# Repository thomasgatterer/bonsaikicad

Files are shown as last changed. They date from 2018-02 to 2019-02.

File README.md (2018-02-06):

# bonsaikicad

Hier die (pädagogisch vereinfachte) Simulation des Lerncomputers:
https://bonsai.pinyto.de/

Und hier die Seite des Lehrers der das Projekt ins Leben gerufen hat (ist übrigens der Vater vom Programmierer der Simulation):
http://www.hsg-kl.de/faecher/inf/material/bonsai/

Weiterführendes:
https://tams-www.informatik.uni-hamburg.de/applets/baukasten/DA/VNR_Einleitung.html
www.saar.de/~awa/data/Von-Neumann-Rechner.pdf
informatik-erleben.aau.at/einheiten/uebersicht.php?id0d3

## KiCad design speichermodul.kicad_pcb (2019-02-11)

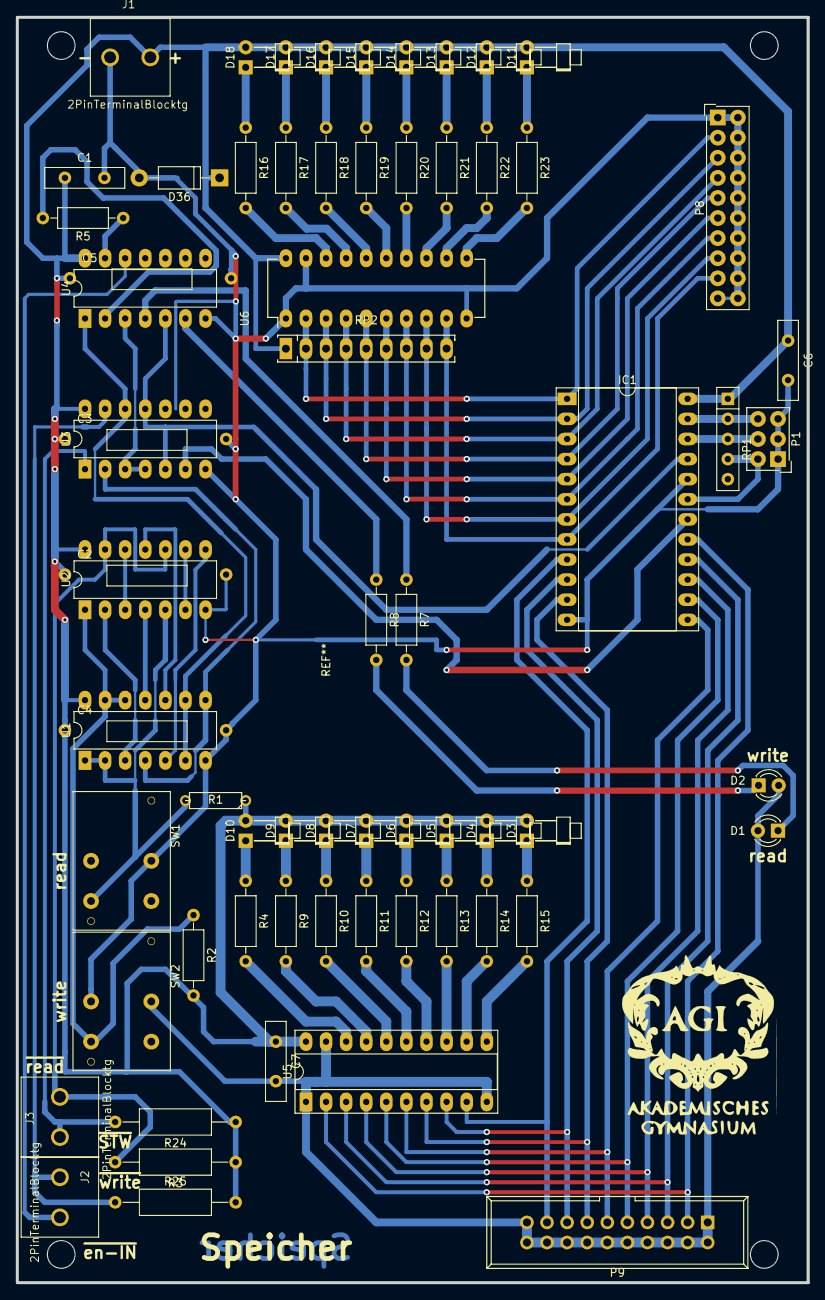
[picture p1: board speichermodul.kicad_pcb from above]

Board: 2 copper layers, 100.0 x 160.0 mm, 67 parts (0 on the bottom side), 76 nets.

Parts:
C1, C6, C7: 100n; C_Disc_D10.0mm_W2.5mm_P5.00mm
C2, C3, C4, C5: 100n; yyDisc_D10.0mm_W2.5mm_P.00mm
D1, D2: LED; LED_D3.0mm
D3, D4, D5, D6, D7, D8, D9, D10, D11, D12, D13, D14, D15, D16, D17, D18: LED; LED_D1.8mm_W1.8mm_H2.4mm_Horizontal_O3.81mm_Z8.2mm
D36: D; D_DO-41_SOD81_P10.16mm_Horizontal
IC1: 6116; DIP-24_W15.24mm_Socket_LongPads
J1, J2, J3: 2PinTerminalBlocktg
P1: CONN_3X2; SDL-106-X-XX_2x03
P8: CONN_02X10; SDL-120-X-XX_2x10
P9: CONN_02X10; IDC_Header_Straight_20pins
R1: 1,7k; R3
R2: 4,7k; R_Axial_DIN0207_L6.3mm_D2.5mm_P10.16mm_Horizontal
R3, R24, R25: 4,7k; R_Axial_DIN0309_L9.0mm_D3.2mm_P15.24mm_Horizontal
R4, R9, R10, R11, R12, R13, R14, R15, R16, R17, R18, R19, R20, R21, R22, R23: 330; R_Axial_DIN0207_L6.3mm_D2.5mm_P10.16mm_Horizontal
R5: 0; R_Axial_DIN0207_L6.3mm_D2.5mm_P10.16mm_Horizontal
R7, R8: R; R_Axial_DIN0207_L6.3mm_D2.5mm_P10.16mm_Horizontal
RP1: R_PACK4BUSSED; R_Array_SIP5
RP2: R_PACK8BUSSED; SIP9_Housing_BigPads
SW1, SW2: SW_PUSH-tg; SW_PUSH_LCD_E3_SAxxxx_tg_V2
U1: 7400; DIP-14_W7.62mm_LongPads
U2, U3: 74LS08; DIP-14_W7.62mm_LongPads
U4: 74LS14; DIP-14_W7.62mm_LongPads
U5: 74LS540; DIP-20_W7.62mm_Socket_LongPads
U6: 74LS540; DIP-20_W7.62mm_LongPads

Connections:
/A0: IC1.1, P8.3, RP2.2, U6.2
/A1: IC1.2, P8.5, RP2.3, U6.3
/A2: IC1.3, P8.7, RP2.4, U6.4
/A3: IC1.4, P8.9, RP2.5, U6.5
/A4: IC1.5, P8.11, RP2.6, U6.6
/A5: IC1.6, P8.13, RP2.7, U6.7
/A6: IC1.7, P8.15, RP2.8, U6.8
/A7: IC1.8, P8.17, RP2.9, U6.9
/A8: IC1.23, P1.2, RP1.2
/A9: IC1.22, P1.4, RP1.3
/A10: IC1.19, P1.6, RP1.4
/D0: IC1.17, P9.3, U5.2
/D1: IC1.16, P9.5, U5.3
/D2: IC1.15, P9.7, U5.4
/D3: IC1.14, P9.9, U5.5
/D4: IC1.13, P9.11, U5.6
/D5: IC1.11, P9.13, U5.7
/D6: IC1.10, P9.15, U5.8
/D7: IC1.9, P9.17, U5.9
AUTO: J3.2, R3.2, U2.10, U2.13
EN: J2.2, U4.12
GND: C1.2, C2.2, C3.2, C4.2, C5.2, C6.2, C7.2, D1.2, D2.2, D36.2, IC1.12, IC1.20, J1.1, P1.1, P1.3, P1.5, P8.1, P8.2, P8.4, P8.6, P8.8, P8.10, P8.12, P8.14, P8.16, P8.18, P8.19, P8.20, P9.1, P9.2, P9.4, P9.6, P9.8, P9.10, P9.12, P9.14, P9.16, P9.18, P9.19, P9.20, SW1.0, SW2.0, U1.7, U2.7, U3.7, U4.7, U5.1, U5.10, U5.19, U6.1, U6.10, U6.19
unnamed: D1.1, R7.2
unnamed: D2.1, R8.2
unnamed: D3.1, R15.1
unnamed: D4.1, R14.1
unnamed: D5.1, R13.1
unnamed: D6.1, R12.1
unnamed: D7.1, R11.1
unnamed: D8.1, R10.1
unnamed: D9.1, R9.1
unnamed: D10.1, R4.1
unnamed: D11.1, R23.1
unnamed: D12.1, R22.1
unnamed: D13.1, R21.1
unnamed: D14.1, R20.1
unnamed: D15.1, R19.1
unnamed: D16.1, R18.1
unnamed: D17.1, R17.1
unnamed: D18.1, R16.1
unnamed: IC1.18, U3.6
unnamed: IC1.21, U3.5, U3.11, U4.5
unnamed: R1.2, SW1.1, U1.1, U1.2, U2.5
unnamed: R2.1, SW2.1, U1.12, U1.13, U2.1
unnamed: R4.2, U5.18
unnamed: R5.1, U4.13
unnamed: R5.2, U4.2
unnamed: R7.1, U4.4
unnamed: R8.1, U4.6
unnamed: R9.2, U5.17
unnamed: R10.2, U5.16
unnamed: R11.2, U5.15
unnamed: R12.2, U5.14
unnamed: R13.2, U5.13
unnamed: R14.2, U5.12
unnamed: R15.2, U5.11
unnamed: R16.2, U6.18
unnamed: R17.2, U6.17
unnamed: R18.2, U6.16
unnamed: R19.2, U6.15
unnamed: R20.2, U6.14
unnamed: R21.2, U6.13
unnamed: R22.2, U6.12
unnamed: R23.2, U6.11
unnamed: U1.3, U2.2
unnamed: U1.4, U1.8, U3.2
unnamed: U1.5, U2.8
unnamed: U1.6, U1.9, U3.12, U4.1
unnamed: U1.10, U2.11
unnamed: U1.11, U2.4
unnamed: U2.6, U2.9
unnamed: U2.3, U2.12
unnamed: U3.3, U3.4, U4.3
RD: J3.1, R24.2, U3.1
VCC: C1.1, C2.1, C3.1, C4.1, C5.1, C6.1, C7.1, D3.2, D4.2, D5.2, D6.2, D7.2, D8.2, D9.2, D10.2, D11.2, D12.2, D13.2, D14.2, D15.2, D16.2, D17.2, D18.2, D36.1, IC1.24, J1.2, R1.1, R2.2, R3.1, R24.1, R25.2, RP1.1, RP2.1, U1.14, U2.14, U3.14, U4.14, U5.20, U6.20
WR: J2.1, R25.1, U3.13

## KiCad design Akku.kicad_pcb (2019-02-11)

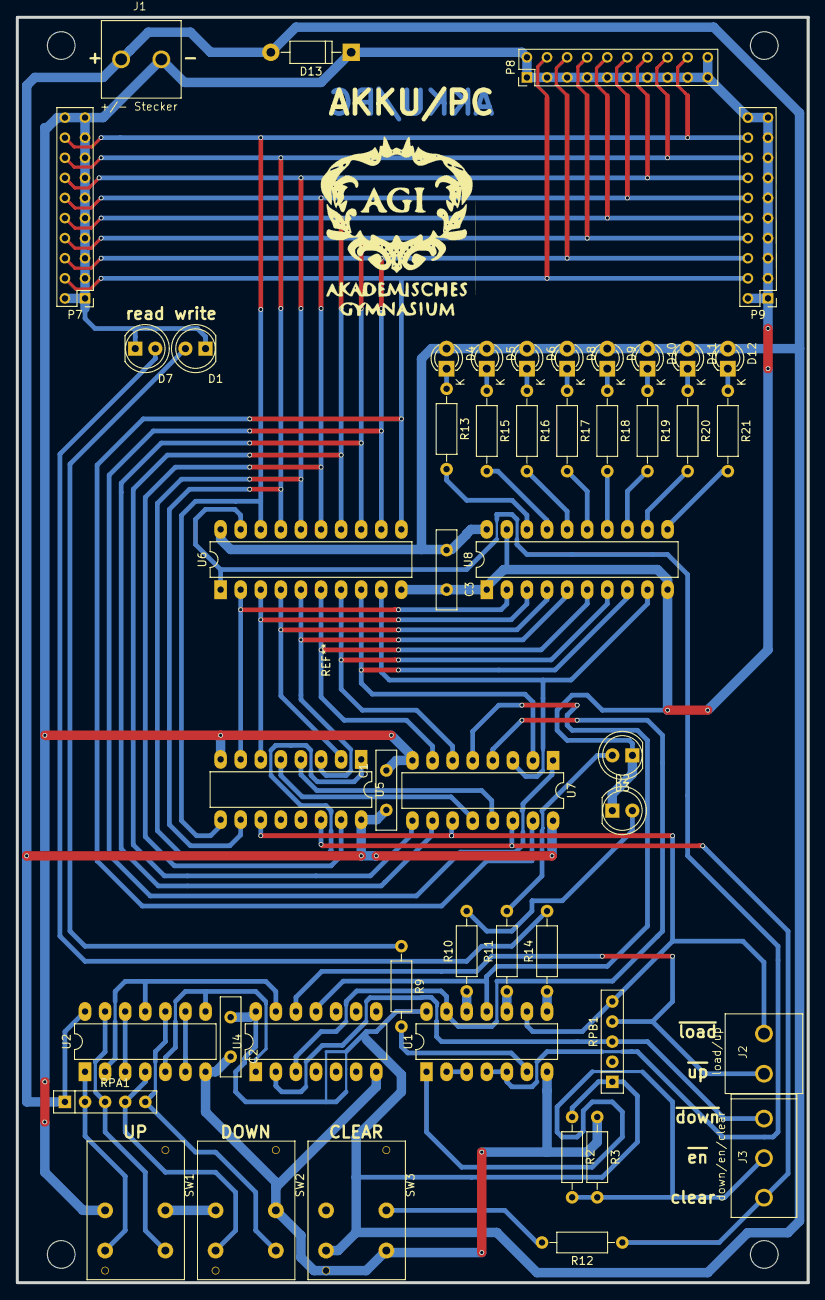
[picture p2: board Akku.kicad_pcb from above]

Board: 2 copper layers, 100.0 x 160.0 mm, 49 parts (0 on the bottom side), 62 nets.

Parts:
C1, C2, C3: C; C_Disc_D10.0mm_W2.5mm_P5.00mm
D1, D2, D3, D7: LED; LED_D5.0mm_FlatTop
D4, D5, D6, D8, D9, D10, D11, D12: LED; LED-3MM
D13: D; D_DO-41_SOD81_P10.16mm_Horizontal
J1: +/- Stecker; 2PinTerminalBlocktg
J2: load/up; 2PinTerminalBlocktg
J3: down/en/clear; 3PinTerminalBlocktg
P7, P8, P9: CONN_02X10; Pin_Header_Straight_2x10_Pitch2.00mmBonsai.pretty
R2, R3, R9, R10, R11, R12, R13, R14, R15, R16, R17, R18, R19, R20, R21: R; R_Axial_DIN0207_L6.3mm_D2.5mm_P10.16mm_Horizontal
RPA1: R_PACK4BUSSED; R_Array_SIP5
RPB1: R_PACK4BUSSED; R_Array_SIP5
SW1: UP_Bonsai_SWITCH_INV; SW_PUSH_LCD_E3_SAxxxx_tg_V2
SW2: DOWN_Bonsai_SWITCH_INV; SW_PUSH_LCD_E3_SAxxxx_tg_V2
SW3: CLR_Bonsai_SWITCH_INV; SW_PUSH_LCD_E3_SAxxxx_tg_V2
U1: 74HC14; DIP-14_W7.62mm_LongPads
U2: 7400; DIP-14_W7.62mm_LongPads
U4: 7408; DIP-14_W7.62mm_LongPads
U5, U7: 74LS193; DIP-16_W7.62mm_LongPads
U6: 74LS541; DIP-20_W7.62mm_LongPads
U8: 74LS540; DIP-20_W7.62mm_LongPads

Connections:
/a0: P7.19, P8.19, P9.19, U5.9, U6.18
/a1: P7.18, P8.18, P9.18, U5.10, U6.17
/a2: P7.17, P8.17, P9.17, U5.1, U6.16
/a3: P7.16, P8.16, P9.16, U5.15, U6.15
/a4: P7.15, P8.15, P9.15, U6.14, U7.9
/a5: P7.14, P8.14, P9.14, U6.13, U7.10
/a6: P7.13, P8.13, P9.13, U6.12, U7.1
/a7: P7.12, P8.12, P9.12, U6.11, U7.15
CLR: J3.3, R12.1, U5.14, U7.14
GND: C1.1, C2.1, C3.1, D1.1, D2.1, D3.1, D7.1, D13.1, J1.2, P7.1, P7.2, P7.3, P7.4, P7.5, P7.6, P7.7, P7.8, P7.9, P7.10, P7.11, P7.20, P8.1, P8.2, P8.3, P8.4, P8.5, P8.6, P8.7, P8.8, P8.9, P8.10, P8.11, P8.20, P9.1, P9.2, P9.3, P9.4, P9.5, P9.6, P9.7, P9.8, P9.9, P9.10, P9.11, P9.20, R3.1, SW1.0, SW2.0, SW3.2, SW3.6, U1.7, U2.7, U4.7, U5.8, U6.10, U7.8, U8.1, U8.10, U8.19
unnamed: D1.2, R9.1
unnamed: D2.2, R10.2
unnamed: D3.2, R11.2
unnamed: D4.1, R13.1
unnamed: D5.1, R15.1
unnamed: D6.1, R16.1
unnamed: D7.2, R14.2
unnamed: D8.1, R17.1
unnamed: D9.1, R18.1
unnamed: D10.1, R19.1
unnamed: D11.1, R20.1
unnamed: D12.1, R21.1
unnamed: R9.2, U1.6
unnamed: R10.1, U1.12
unnamed: R11.1, U1.10
unnamed: R12.2, SW3.0
unnamed: R13.2, U8.18
unnamed: R14.1, U1.8
unnamed: R15.2, U8.17
unnamed: R16.2, U8.16
unnamed: R17.2, U8.15
unnamed: R18.2, U8.14
unnamed: R19.2, U8.13
unnamed: R20.2, U8.12
unnamed: R21.2, U8.11
unnamed: U1.2, U1.3
unnamed: U1.4, U1.5, U6.1, U6.19
unnamed: U1.11, U4.11, U7.5
unnamed: U1.13, U4.3, U7.4
unnamed: U2.5, U2.8, U4.1
unnamed: U2.6, U2.9
unnamed: U2.2, U2.11, U4.13
unnamed: U2.3, U2.12
unnamed: U5.2, U6.4, U8.4
unnamed: U5.3, U6.5, U8.5
unnamed: U5.4, U7.13
unnamed: U5.5, U7.12
unnamed: U5.6, U6.3, U8.3
unnamed: U5.7, U6.2, U8.2
unnamed: U6.6, U7.7, U8.6
unnamed: U6.7, U7.6, U8.7
unnamed: U6.8, U7.2, U8.8
unnamed: U6.9, U7.3, U8.9
RPA1: RPA1.2, SW1.1, U2.1
RPA2: RPA1.3, SW1.2, U2.13
RPA3: RPA1.4, SW2.1, U2.4
RPA4: RPA1.5, SW2.2, U2.10
RPB2: J3.1, RPB1.3, U4.2
RPB3: J2.2, RPB1.4, U4.12
RPB4: J2.1, RPB1.5, U1.9, U5.11, U7.11
VCC: C1.2, C2.2, C3.2, D4.2, D5.2, D6.2, D8.2, D9.2, D10.2, D11.2, D12.2, D13.2, J1.1, R2.1, RPA1.1, RPB1.1, SW3.1, U1.14, U2.14, U4.14, U5.16, U6.20, U7.16, U8.20
^enable: J3.2, R2.2, R3.2, U1.1

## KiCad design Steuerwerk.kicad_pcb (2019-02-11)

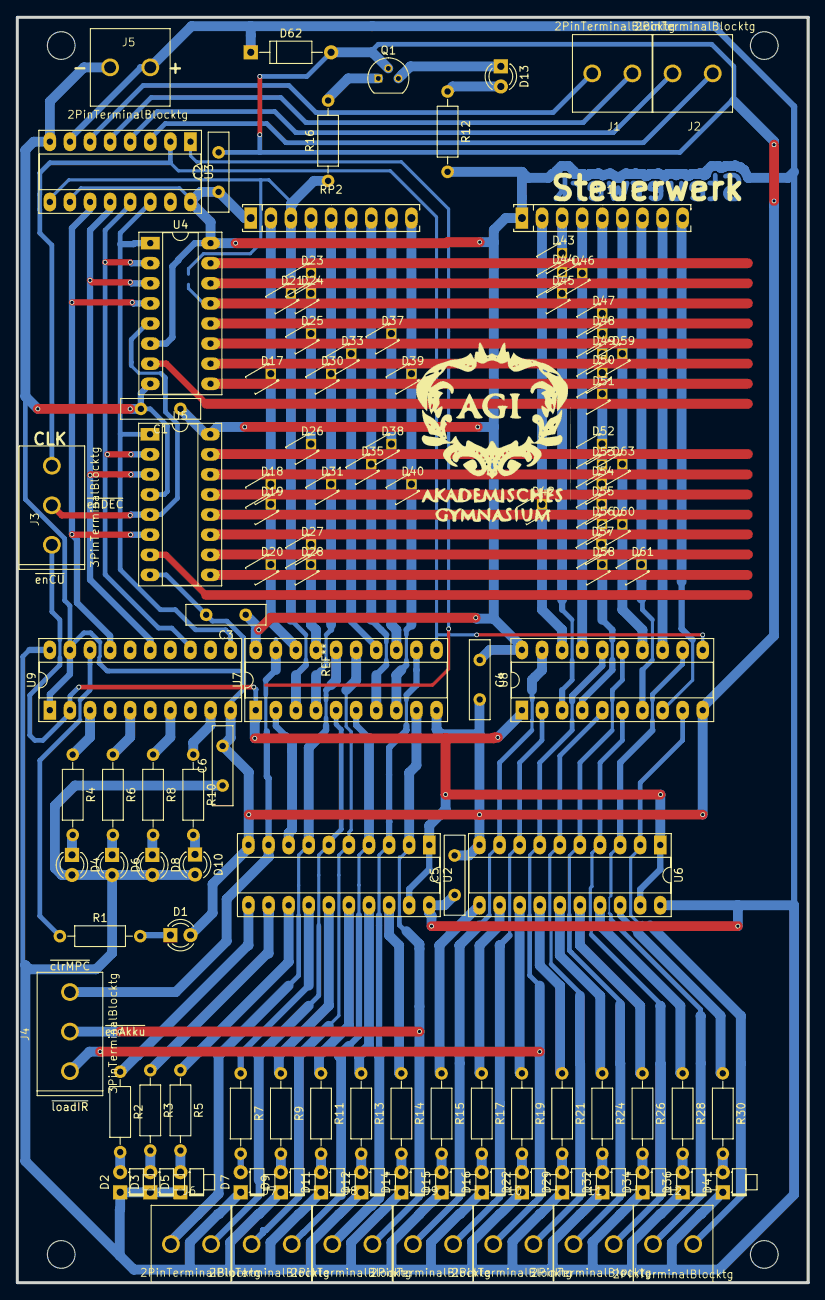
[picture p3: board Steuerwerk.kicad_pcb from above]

Board: 2 copper layers, 100.0 x 160.0 mm, 115 parts (0 on the bottom side), 104 nets.

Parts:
C1, C2, C3, C4, C5, C6: 100n; C_Disc_D10.0mm_W2.5mm_P5.00mm
D1, D4, D6, D8, D10, D13: LED; LED_D3.0mm
D2, D3, D5, D7, D9, D11, D12, D14, D15, D16, D22, D29, D32, D34, D36, D41: LED; LED_D1.8mm_W1.8mm_H2.4mm_Horizontal_O1.27mm_Z1.6mm
D17, D18, D19, D20, D21, D23, D24, D25, D26, D27, D28, D30, D31, D33, D35, D37, D38, D39, D40, D42, D43, D44, D45, D46, D47, D48, D49, D50, D51, D52, D53, D54, D55, D56, D57, D58, D59, D60, D61, D63: Led_Small; LED_D1.8mm_W3.3mm_H2.4mmBonsai
D62: D; D_A-405_P10.16mm_Horizontal
J1, J2, J5, J6, J7, J8, J9, J10, J11, J12: 2PinTerminalBlocktg
J3, J4: 3PinTerminalBlocktg
Q1: Q_PNP_BCE; TO-92_Molded_Narrow
R1, R2, R3, R4, R5, R6, R7, R8, R9, R10, R11, R12, R13, R14, R15, R16, R17, R19, R21, R24, R26, R28, R30: R; R_Axial_DIN0207_L6.3mm_D2.5mm_P10.16mm_Horizontal
RP1, RP2: R_PACK8BUSSED; SIP9_Housing_BigPads
U2, U6: 74541; DIP-20_W7.62mm_Socket_LongPads
U3: 74LS161; DIP-16_W7.62mm_Socket_LongPads
U4, U5: 74LS138; DIP-16_W7.62mm_Socket_LongPads
U7: 74LS374; DIP-20_W7.62mm_Socket_LongPads
U8: 74LS374; DIP-20_W7.62mm_Socket_LongPadstg
U9: 74ls240; DIP-20_W7.62mm_Socket_LongPads

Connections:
/3: J6.1, U2.7, U7.16
/5: J7.1, U2.5, U7.15
/7: J8.1, U2.3, U7.12
/9: J9.1, U6.9, U8.19
/11: J4.1, J10.1, U6.7, U8.16
/13: J11.1, U6.5, U8.15
/15: J12.1, U6.3, U8.12
/16: J12.2, U6.2, U8.9
/Takt: J3.3, U3.2, U7.11, U8.11
/a1: D17.1, D18.1, D19.1, D20.1, RP2.2, U7.18
/a2: D21.1, R16.1, RP2.3, U3.9, U7.3
/a3: D23.1, D24.1, D25.1, D26.1, D27.1, D28.1, RP2.4, U7.17
/a4: D30.1, D31.1, RP2.5, U7.4
/a5: D33.1, RP2.6, U7.14
/a6: D35.1, RP2.7, U7.7
/a7: D37.1, D38.1, RP2.8, U7.13
/a8: D39.1, D40.1, RP2.9, U7.8
/b1: D42.1, RP1.2, U8.18
/b2: D43.1, D44.1, D45.1, RP1.3, U8.3
/b3: D46.1, RP1.4, U8.17
/b4: D47.1, D48.1, D49.1, D50.1, D51.1, D52.1, D53.1, D54.1, D55.1, D56.1, D57.1, D58.1, RP1.5, U8.4
/b5: D59.1, D60.1, D63.1, RP1.6, U8.14
/b6: D61.1, RP1.7, U8.7
/b7: RP1.8, U8.13
/b8: RP1.9, U8.8
/clrMPC: J4.3, U2.9, U3.1, U7.19
/enAkku: J4.2, J8.2, U2.2, U7.9
/enDEC: J3.2, U4.5, U5.5
/enSTW: J3.1, U2.1, U2.19, U6.1, U6.19, U7.1, U8.1, U9.2
GND: C1.2, C2.2, C3.2, C4.2, C5.2, C6.2, D1.2, D62.2, J5.1, Q1.2, U2.10, U3.8, U4.8, U5.4, U5.8, U6.10, U7.10, U8.10, U9.1, U9.10, U9.19
unnamed: D1.1, R1.2
unnamed: D2.2, R2.2
unnamed: D3.2, R3.2
unnamed: D4.1, R4.2
unnamed: D5.2, R5.2
unnamed: D6.1, R6.2
unnamed: D7.2, R7.2
unnamed: D8.1, R8.2
unnamed: D9.2, R9.2
unnamed: D10.1, R10.2
unnamed: D11.2, R11.2
unnamed: D12.2, R13.2
unnamed: D13.1, Q1.3
unnamed: D13.2, R12.1
unnamed: D14.2, R14.2
unnamed: D15.2, R15.2
unnamed: D16.2, R17.2
unnamed: D17.2, D30.2, D39.2, D50.2, U4.9
unnamed: D18.2, D31.2, D40.2, D54.2, U5.13
unnamed: D19.2, D42.2, D55.2, U5.12
unnamed: D20.2, D28.2, D58.2, D61.2, U5.9
unnamed: D21.2, D24.2, D45.2, U4.13
unnamed: D22.2, R19.2
unnamed: D23.2, D44.2, D46.2, U4.14
unnamed: D25.2, D37.2, D48.2, U4.11
unnamed: D26.2, D38.2, D52.2, U5.15
unnamed: D27.2, D57.2, U5.10
unnamed: D29.2, R21.2
unnamed: D32.2, R24.2
unnamed: D33.2, D49.2, D59.2, U4.10
unnamed: D34.2, R26.2
unnamed: D35.2, D53.2, D63.2, U5.14
unnamed: D36.2, R28.2
unnamed: D41.2, R30.2
unnamed: D43.2, U4.15
unnamed: D47.2, U4.12
unnamed: D51.2, U4.7
unnamed: D56.2, D60.2, U5.11
unnamed: J1.1, U3.5
unnamed: J1.2, U3.6
unnamed: J2.1, U3.3
unnamed: J2.2, U3.4
unnamed: J6.2, U2.6, U7.5
unnamed: J7.2, U2.4, U7.6
unnamed: J9.2, U6.8, U8.2
unnamed: J10.2, U6.6, U8.5
unnamed: J11.2, U6.4, U8.6
unnamed: Q1.1, R16.2
unnamed: R1.1, U9.18
unnamed: R2.1, U2.11
unnamed: R3.1, U2.12
unnamed: R4.1, U9.3
unnamed: R5.1, U2.13
unnamed: R6.1, U9.5
unnamed: R7.1, U2.14
unnamed: R8.1, U9.7
unnamed: R9.1, U2.15
unnamed: R10.1, U9.9
unnamed: R11.1, U2.16
unnamed: R13.1, U2.17
unnamed: R14.1, U2.18
unnamed: R15.1, U6.11
unnamed: R17.1, U6.12
unnamed: R19.1, U6.13
unnamed: R21.1, U6.14
unnamed: R24.1, U6.15
unnamed: R26.1, U6.16
unnamed: R28.1, U6.17
unnamed: R30.1, U6.18
unnamed: U3.11, U4.4, U5.6, U9.17
unnamed: U3.12, U4.3, U5.3, U9.15
unnamed: U3.13, U4.2, U5.2, U9.13
unnamed: U3.14, U4.1, U5.1, U9.11
VCC: C1.1, C2.1, C3.1, C4.1, C5.1, C6.1, D2.1, D3.1, D4.2, D5.1, D6.2, D7.1, D8.2, D9.1, D10.2, D11.1, D12.1, D14.1, D15.1, D16.1, D22.1, D29.1, D32.1, D34.1, D36.1, D41.1, D62.1, J5.2, R12.2, RP1.1, RP2.1, U2.20, U3.7, U3.10, U3.16, U4.6, U4.16, U5.16, U6.20, U7.20, U8.20, U9.20

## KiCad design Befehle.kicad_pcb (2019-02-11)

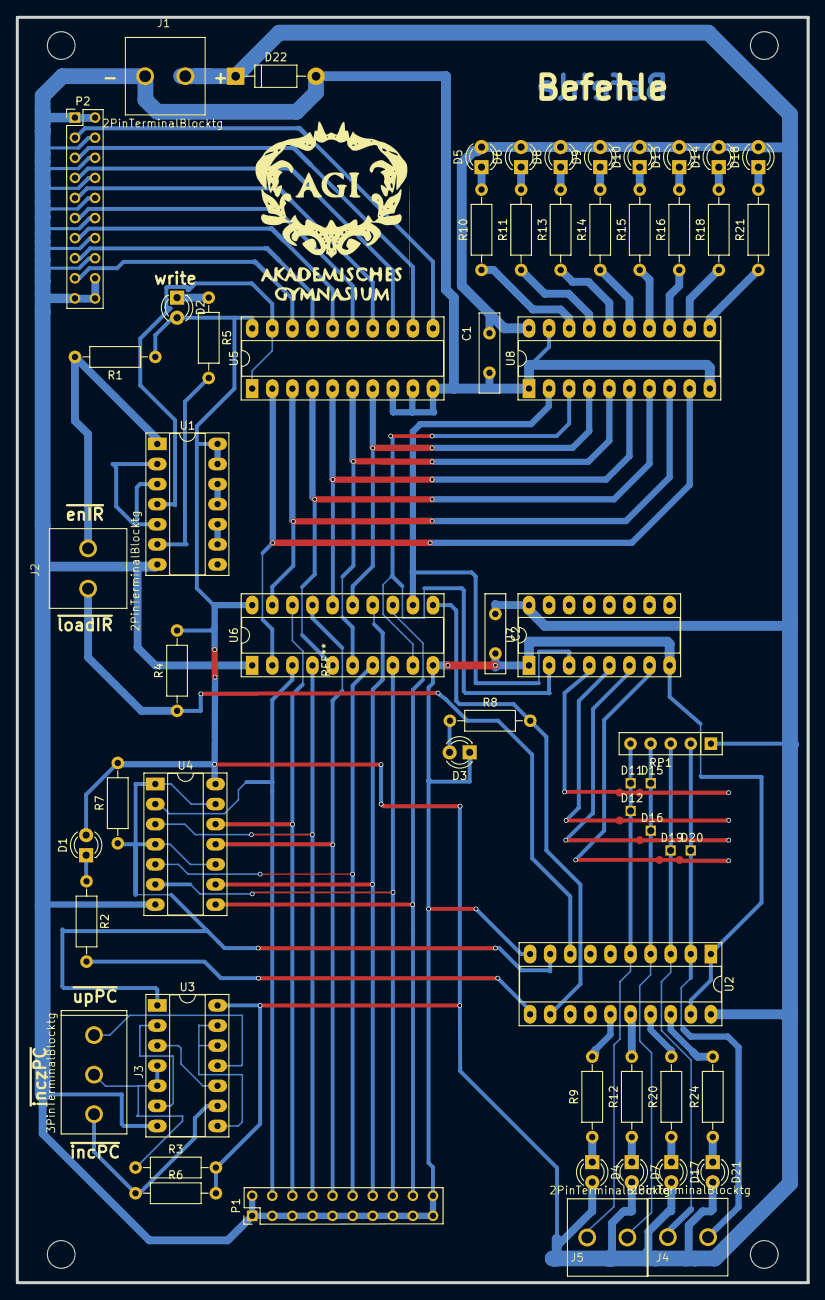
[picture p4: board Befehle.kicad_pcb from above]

Board: 2 copper layers, 100.0 x 160.0 mm, 60 parts (0 on the bottom side), 77 nets.

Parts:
C1, C2: 100n; C_Disc_D10.0mm_W2.5mm_P5.00mm
D1, D3, D4, D7, D17, D18, D21: LED; LED_D3.0mm
D2, D5, D6, D8, D9, D10, D13, D14: Led_Small; LED_D3.0mm
D11, D12, D15, D16, D19, D20: Led_Small; Diode_D1.8mm_W3.3mm_H2.4mmBonsai
D22: D; D_DO-41_SOD81_P10.16mm_Horizontal
J1, J2, J4, J5: 2PinTerminalBlocktg
J3: 3PinTerminalBlocktg
P1, P2: CONN_02X10; Pin_Header_Straight_2x10_Pitch2.00mmBonsai.pretty
R1, R3, R4, R6: 4,7k; R_Axial_DIN0207_L6.3mm_D2.5mm_P10.16mm_Horizontal
R2, R5, R8, R9, R10, R11, R12, R13, R14, R15, R16, R18, R20, R21, R24: 330; R_Axial_DIN0207_L6.3mm_D2.5mm_P10.16mm_Horizontal
R7: 1k; R_Axial_DIN0207_L6.3mm_D2.5mm_P10.16mm_Horizontal
RP1: R_PACK4BUSSED; R_Array_SIP5
U1: 74LS14; DIP-14_W7.62mm_Socket_LongPadstg
U2: 74540; DIP-20_W7.62mm_Socket_LongPadstg
U3: 7400; DIP-14_W7.62mm_Socket_LongPadstg
U4: 74HCT02; DIP-14_W7.62mm_Socket_LongPadstg
U5: 74LS541; DIP-20_W7.62mm_Socket_LongPadstg
U6: 74LS373; DIP-20_W7.62mm_Socket_LongPadstg
U7: 74LS139; DIP-16_W7.62mm_Socket_LongPadstg
U8: 74LS540; DIP-20_W7.62mm_Socket_LongPadstg

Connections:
0: D20.1, J4.1, RP1.2, U2.2
1: D19.1, J4.2, RP1.3, U2.3
2: D15.1, D16.1, J5.1, RP1.4, U2.4
3: D11.1, D12.1, J5.2, RP1.5, U2.5
/a1: U5.2, U6.2, U8.9
/a2: U5.3, U6.19, U8.8
/a3: U5.4, U6.5, U8.7
/a4: U6.12, U7.3, U8.2
/a5: U5.6, U6.6, U8.5
/a6: U5.7, U6.15, U8.4
/a7: U6.9, U7.2, U8.3
/a8: U5.5, U6.16, U8.6
/d1: P1.13, U4.12, U6.18
/d2: P1.12, U4.2, U6.3
/d3: P1.15, U4.11, U6.17
/d4: P1.19, U4.8, U6.13
/d5: P1.17, U4.9, U6.14
/d6: P1.18, U4.6, U6.8
/d7: P1.14, U4.3, U6.4
/d44: P1.16, U4.5, U6.7
GND: C1.2, C2.2, D3.1, D22.2, J1.1, P1.1, P1.2, P1.3, P1.4, P1.5, P1.6, P1.7, P1.8, P1.9, P1.10, P1.11, P1.20, P2.1, P2.10, P2.11, P2.12, P2.13, P2.14, P2.15, P2.16, P2.17, P2.18, P2.19, P2.20, U1.7, U2.1, U2.10, U2.19, U3.7, U4.7, U5.8, U5.9, U5.10, U6.1, U6.10, U7.1, U7.8, U8.1, U8.10, U8.19
unnamed: D1.1, R2.1
unnamed: D2.1, R5.1
unnamed: D3.2, R8.1
unnamed: D4.1, R9.1
unnamed: D5.1, R10.2
unnamed: D6.1, R11.2
unnamed: D7.1, R12.1
unnamed: D8.1, R13.2
unnamed: D9.1, R14.2
unnamed: D10.1, R15.2
unnamed: D11.2, D15.2, U7.4
unnamed: D12.2, U7.5
unnamed: D13.1, R16.2
unnamed: D14.1, R18.2
unnamed: D16.2, U7.6
unnamed: D17.1, R20.1
unnamed: D18.1, R21.2
unnamed: D19.2, D20.2, U7.7
unnamed: D21.1, R24.1
unnamed: P2.2, U5.11
unnamed: P2.3, U5.12
unnamed: P2.4, U5.13
unnamed: P2.5, U5.14
unnamed: P2.6, U5.15
unnamed: P2.7, U5.16
unnamed: P2.8, U5.17
unnamed: P2.9, U5.18
unnamed: R2.2, U2.11
unnamed: R5.2, U1.6
unnamed: R7.1, U2.9, U3.1, U4.1, U4.4, U4.10, U4.13
unnamed: R8.2, U2.12, U6.11
unnamed: R9.2, U2.15
unnamed: R10.1, U8.18
unnamed: R11.1, U8.17
unnamed: R12.2, U2.16
unnamed: R13.1, U8.16
unnamed: R14.1, U8.15
unnamed: R15.1, U8.14
unnamed: R16.1, U8.13
unnamed: R18.1, U8.12
unnamed: R20.2, U2.17
unnamed: R21.1, U8.11
unnamed: R24.2, U2.18
unnamed: U1.2, U1.3, U1.5
unnamed: U1.4, U5.1, U5.19
unnamed: U1.9, U1.10
unnamed: U1.11, U1.12
unnamed: U3.2, U3.6
unnamed: U3.3, U3.10
unnamed: U3.8, U3.12, U3.13
VCC: C1.1, C2.1, D1.2, D2.2, D4.2, D5.2, D6.2, D7.2, D8.2, D9.2, D10.2, D13.2, D14.2, D17.2, D18.2, D21.2, D22.1, J1.2, R1.1, R3.2, R4.2, R6.2, R7.2, RP1.1, U1.13, U1.14, U2.20, U3.14, U4.14, U5.20, U6.20, U7.16, U8.20
enableR: J2.2, R1.2, U1.1
incPC: J3.3, R6.1, U3.9
incPCz: J3.2, R3.1, U3.4, U3.5
loadIR: J2.1, R4.1, U2.8
upPC: J3.1, U3.11

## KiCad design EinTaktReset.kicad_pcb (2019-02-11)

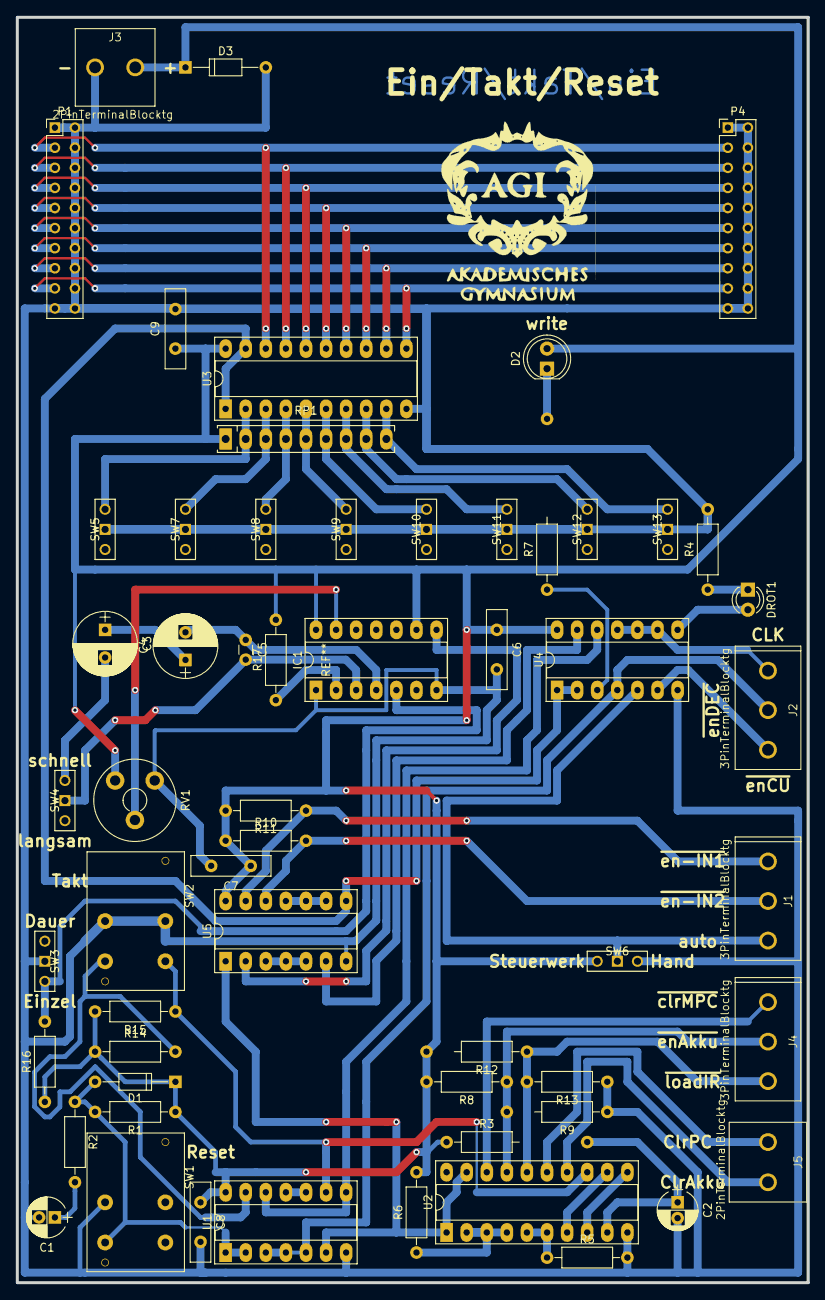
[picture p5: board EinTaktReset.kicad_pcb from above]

Board: 2 copper layers, 100.0 x 160.0 mm, 58 parts (0 on the bottom side), 57 nets.

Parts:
C1: 47µ; CP_Radial_D5.0mm_P2.00mm
C2: 10 µ; CP_Radial_D5.0mm_P2.00mm
C3: 220 µ; CP_Radial_D8.0mm_P3.50mm
C4: 220µ; CP_Radial_D8.0mm_P3.50mm
C5: 10n; C_Disc_D3.0mm_W1.6mm_P2.50mm
C6, C7, C8, C9: 100n; C_Disc_D10.0mm_W2.5mm_P5.00mm
D1, D3: D; D_DO-35_SOD27_P10.16mm_Horizontal
D2: LED; LED_D5.0mm
DROT1: LED; LED_D3.0mm
IC1: 74LS624; DIP-14_W7.62mm_Socket_LongPads
J1, J2, J4: 3PinTerminalBlocktg
J3, J5: 2PinTerminalBlocktg
P1, P4: CONN_02X10; Pin_Header_Straight_2x10_Pitch2.00mmBonsai.pretty
R1, R17: 10k; R_Axial_DIN0207_L6.3mm_D2.5mm_P10.16mm_Horizontal
R2: 100; R_Axial_DIN0207_L6.3mm_D2.5mm_P10.16mm_Horizontal
R3: 10k; R_Axial_DIN0207_L6.3mm_D2.5mm_P17.7mm_Horizontaltg
R4: 150; R_Axial_DIN0207_L6.3mm_D2.5mm_P10.16mm_Horizontal
R5, R6: 470; R_Axial_DIN0207_L6.3mm_D2.5mm_P10.16mm_Horizontal
R7: 330; R_Axial_DIN0207_L6.3mm_D2.5mm_P21.59mm_Horizontaltg
R8: 1,8k; R_Axial_DIN0207_L6.3mm_D2.5mm_P10.16mm_Horizontal
R9: 2,2k; R_Axial_DIN0207_L6.3mm_D2.5mm_P12.7mm_Horizontaltg
R10, R11, R14, R15, R16: 4,7k; R_Axial_DIN0207_L6.3mm_D2.5mm_P10.16mm_Horizontal
R12: 1,8k; R_Axial_DIN0207_L6.3mm_D2.5mm_P12.7mm_Horizontaltg
R13: 2,2k; R_Axial_DIN0207_L6.3mm_D2.5mm_P10.16mm_Horizontal
RP1: R_PACK8BUSSED; SIP9_Housing_BigPads
RV1: POT; Potentiometer_Trimmer_Piher_PT-10v5_Horizontal_Px5.0mm_Py5.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
SW1, SW2: SWITCH_INV; SW_PUSH_LCD_E3_SAxxxx_tg_V2
SW3, SW4, SW5, SW7, SW8, SW9, SW10, SW11, SW12, SW13: SPST; eintakt_tg_SW_CuK_JS202011CQN_DPDT_Straight
SW6: SWITCH_INV; eintakt_tg_SW_CuK_JS202011CQN_DPDT_Straight
U1: 74LS132; DIP-14_W7.62mm_Socket_LongPads
U2: 74540En; DIP-20_W7.62mm_Socket_LongPads
U3: 74HCT541_PWR; DIP-20_W7.62mm_Socket_LongPads
U4: 74LS32; DIP-14_W7.62mm_Socket_LongPads
U5: 74LS00; DIP-14_W7.62mm_Socket_LongPads

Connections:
/a0: P1.2, P4.2, U3.18
/a1: P1.3, P4.3, U3.17
/a2: P1.4, P4.4, U3.16
/a3: P1.5, P4.5, U3.15
/a4: P1.6, P4.6, U3.14
/a5: P1.7, P4.7, U3.13
/a6: P1.8, P4.8, U3.12
/a7: P1.9, P4.9, U3.11
CLK: J2.1, U4.9, U4.10, U4.11
GND: C1.2, C2.2, C6.2, C7.2, C8.2, C9.2, D3.2, IC1.1, IC1.7, J3.1, P1.1, P1.10, P1.11, P1.12, P1.13, P1.14, P1.15, P1.16, P1.17, P1.18, P1.19, P1.20, P4.1, P4.10, P4.11, P4.12, P4.13, P4.14, P4.15, P4.16, P4.17, P4.18, P4.19, P4.20, R4.2, R5.2, R9.1, R13.1, RV1.3, SW1.0, SW2.0, SW3.1, SW5.1, SW6.2, SW7.1, SW8.1, SW9.1, SW10.1, SW11.1, SW12.1, SW13.1, U1.7, U2.10, U3.10, U4.7, U5.7
unnamed: C1.1, R2.2
unnamed: C2.1, R3.2, U2.9
unnamed: C3.1, C4.1
unnamed: C3.2, SW4.2
unnamed: C4.2, C5.1, IC1.4
unnamed: C5.2, IC1.3, SW4.1
unnamed: D1.2, R1.2, R2.1, SW1.1, U1.1, U1.2
unnamed: D2.1, R7.2
unnamed: DROT1.1, R4.1
unnamed: DROT1.2, U4.8
unnamed: IC1.2, R17.1
unnamed: IC1.5, R16.2, SW3.2
unnamed: IC1.8, U5.2
unnamed: IC1.13, RV1.2
unnamed: R5.1, U2.5, U2.6
unnamed: R6.1, U2.2, U2.3, U2.4
unnamed: R7.1, U4.3
unnamed: R14.2, SW2.1, U1.13
unnamed: R15.1, SW2.2, U1.9, U2.13
unnamed: RP1.2, SW5.2, U3.2
unnamed: RP1.3, SW7.2, U3.3
unnamed: RP1.4, SW8.2, U3.4
unnamed: RP1.5, SW9.2, U3.5
unnamed: RP1.6, SW10.2, U3.6
unnamed: RP1.7, SW11.2, U3.7
unnamed: RP1.8, SW12.2, U3.8
unnamed: RP1.9, SW13.2, U3.9
unnamed: U1.6, U2.1, U2.19, U5.1
unnamed: U1.10, U1.11
unnamed: U1.8, U1.12, U4.12
unnamed: U2.8, U2.11
unnamed: U2.7, U2.12
unnamed: U3.1, U3.19, U4.1, U4.2, U5.8
unnamed: U4.13, U5.6
unnamed: U5.3, U5.4, U5.5
unnamed: U5.9, U5.10, U5.11
VCC: C6.1, C7.1, C8.1, C9.1, D1.1, D2.2, D3.1, IC1.9, IC1.14, J3.2, R1.1, R3.1, R6.2, R8.2, R10.1, R11.2, R12.2, R14.1, R15.2, R16.1, R17.2, RP1.1, RV1.1, SW6.0, U1.14, U3.20, U4.14, U5.14
auto: J1.3, SW6.1, U4.5
clrAkku: J5.2, U2.14
clrMPC: J4.1, U2.18
clrPC: J5.1, U2.15
en-ln1: J1.1, R11.1, U5.13
en-ln2: J1.2, R10.2, U5.12
enAkku: J4.2, R8.1, R9.2, U2.17
enDEC: J2.2, U1.3, U1.4, U1.5, U4.4
enSTW: J2.3, U4.6
loadIR: J4.3, R12.1, R13.2, U2.16

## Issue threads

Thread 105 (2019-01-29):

speicher, eintakt, switches auf V2 ändern (korrigierte größe)

thomasgatterer, 2019-01-29:

Closed 2019-02-11.

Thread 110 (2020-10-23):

Steuerwerk fehlende Durchkontaktierung

thomasgatterer, 2020-10-23:
Problem mit dem Steuersignal 1 (clrMPC): Auf der Platine fehlt scheinbar eine Durchkontaktierung unter dem IC U7 (vgl. Bild). Eigentlich sollte zwischen Pin 1 von U3 und Pin 19 von U7 eine Verbindung bestehen.

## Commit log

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2016-09-09 additions and corrections
    [speichermodul.sch]
2016-09-10 switch to kicad 4
    [speichermodul.sch]
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2016-09-16 changed version to Nightly Development Build for missing footprints
    [speichermodul.sch]
2016-10-03 AKKU von Simon zum Projekt hinzugefügt
    [Akku.kicad_pcb, Akku.sch]
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2016-10-17 add footprints to speichermodul
    [speichermodul.kicad_pcb]
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2016-11-07 Schaltplan (wie mit T. Gatterer besprochen) fertiggestellt. Annotations. Footprints begonnen.
    [Akku.sch, _saved_speichermodul.sch]
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2016-12-05 Akku Schaltplan fast fertiggestellt; PCB angefangen.
    [Akku.sch]
2016-12-05 Befehle Speicherplan fast fertig
    [Befehle.sch]
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2016-12-19 Fehler am Schaltplan ausgebessert; PCB erweitert
    [Akku.kicad_pcb, Akku.sch]
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2017-03-13 einige Leds und Resistoren hinzugefügt und ausgebessert
    [speichermodul.kicad_pcb, speichermodul.sch]
2017-03-13 Footprints ausgebessert und die Positionierung der Bauteile begonnen
    [Befehle.kicad_pcb, Befehle.sch]
2017-03-13 pcb weiter verschobene bauteile
    [speichermodul.kicad_pcb]
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2017-03-20 Befehle Footprints und Leiterbahnen added
    [Befehle.kicad_pcb, Befehle.sch]
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2017-11-22 Akku.sch verändert, Components ausgetauscht
    [Akku.sch]
2017-11-22 Pcb layout und neue footprints eingefügt
    [speichermodul.kicad_pcb]
2017-11-29 neue Steuerwerk Resistoren mit dateien
    [Steuerwerk.kicad_pcb, Steuerwerk.sch]
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2017-11-29 .sch datei leicht verändert
    [EinTaktReset.sch]
2017-11-29 Kabel verlegen und pcb layout
    [speichermodul.kicad_pcb, speichermodul.sch]
2017-11-30 lib 74540 added ACHTUNG: Versionsprobleme checken
    [Befehle.sch]
2017-12-06 Akku Namen Problem behoben
    [Akku.kicad_pcb]
2017-12-06 changes in eintaktreset .sch
    [EinTaktReset.sch]
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2017-12-13 changes in eintaktres .sch
    [EinTaktReset.sch]
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2017-12-14 reset logic added
    [EinTaktReset.sch]
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2017-12-19 busverbindungen in eintaktreset fertig gezeichnet
    [EinTaktReset.sch]
2017-12-20 fehlende Chips und Komponenten hinzugefügt
    [Steuerwerk.sch]
2017-12-20 Pcb layout perfektioniert und schaltplan vorangetrieben
    [speichermodul.kicad_pcb, speichermodul.sch]
2017-12-20 resistors added,label and output pins added
    [EinTaktReset.sch]
2017-12-20 footprints bearbeitet und geordnet
    [Befehle.kicad_pcb, Befehle.sch]
2017-12-20 Akku.sch fertiggestellt, Footprintfehler behoben, PCB Grundauslegung begonnen
    [Akku.neu.kicad_pcb, Akku.sch]
2017-12-22 Version changegit status! footprints, pcb speichermodul
    [speichermodul.kicad_pcb, speichermodul.sch]
2017-12-22 speichermodul to new version
    [Steuerwerk.sch, _saved_speichermodul.sch]
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2017-12-23 Akku to new kicad version
    [Akku.sch]
2017-12-23 befehle.sch to new kicad version
    [Befehle.sch]
2017-12-23 Eintakt.sch to new kicad version
    [EinTaktReset.sch]
2017-12-23 Eintakt bugfixing ERC (more or less) done
    [EinTaktReset.sch]
2017-12-24 part changed 240 in lib added
    [Steuerwerk.sch]
2017-12-25 74541 output series (south) corrected, tackt, enDec, enSTW, clrMPC, enAkku, laodIR checked
    [Steuerwerk.kicad_pcb, Steuerwerk.sch]
2017-12-25 Steuerwerk: some minor fixes
    [Steuerwerk.sch]
2017-12-25 Steuerwerk: 74ls161 (nort west) adapted labels and error corrections
    [Steuerwerk.sch]
2017-12-26 steuerwerk: .sch almost debuged
    [Steuerwerk.sch]
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2018-01-07 Befehle Footprints and 74540 part order fixed
    [Befehle.kicad_pcb, Befehle.sch]
2018-01-11 names and footprints fixes
    [EinTaktReset.kicad_pcb, EinTaktReset.sch]
2018-01-16 EinTaktReset checked, no ? found
    [EinTaktReset.sch]
2018-01-16 RPacked 5Pinns in Befehle und Speicher added and some strange fixes (not connected pins ...)
    [Befehle.sch, speichermodul.sch]
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2018-01-17 library tmptg... fixtried
    [EinTaktReset.sch]
2018-01-17 Ordnen der Teile im PCB
    [_saved_Steuerwerk.sch]
2018-01-17 alles neu, also alles
    [Akku.kicad_pcb, Akku.sch]
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2018-01-21 diodes under res array Befehle are now smaler
    [Befehle.kicad_pcb, Befehle.sch]
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2018-01-24 units von U2 74541 organisieren
    [_saved_Steuerwerk.sch]
2018-01-24 Speichern vergessen ( jetzt nachgeholt)
    [Steuerwerk.kicad_pcb, Steuerwerk.sch, _saved_Steuerwerk.sch]
2018-01-24 resistoren footprint ausgetsauscht (nicht fertig)
    [Befehle.kicad_pcb, Befehle.sch]
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2018-01-31 problems solved and capacitors footprinted
    [EinTaktReset.sch]
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2018-02-21 textlabel für fehlende footprints in eintakt.sch added
    [EinTaktReset.sch]
2018-02-27 footprint IC1 ls624 VCO 14 pin
    [EinTaktReset.kicad_pcb, EinTaktReset.sch]
2018-02-27 footprint d1 smal diode do35 added
    [EinTaktReset.kicad_pcb, EinTaktReset.sch]
2018-02-27 ic1 vco lib problem solved
    [EinTaktReset.kicad_pcb, EinTaktReset.sch]
2018-02-27 falsches gehäuse ic1 vco
    [EinTaktReset.kicad_pcb, EinTaktReset.sch]
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2018-02-28 Diode added, pins in 3erpins zusammengefasst, fehler beim speichern
    [EinTaktReset.sch]
2018-02-28 diode und erste pins
    [Befehle.kicad_pcb, Befehle.sch]
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2018-03-29 Schraub Anschlüsse zum Steuerwerk hinzugefügt
    [Steuerwerk.sch]
2018-03-29 Schrauben Klemmen wegen library arbeit wieder entfernt
    [EinTaktReset.sch]
2018-03-29 Library Test put old Libs in bonsaicomplib
    [EinTaktReset.sch]
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2018-03-30 library bugs solved (old libs renamed in project)
    [Akku.sch, Steuerwerk.sch]
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2018-04-02 Steuerwerk: new smal LED custom lib and various bugfixes
    [Steuerwerk.kicad_pcb, Steuerwerk.sch]
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2018-04-18 R2-R22 ausgetauscht und Buttons (footprints), todolist anglegt, Bauteile angeordnet (80%)
    [Akku.kicad_pcb, Akku.neu.kicad_pcb, Akku.sch]
2018-04-18 pcb gelayoutet, footprint für capacitors geadded, 74ls32 teile zugeordnet, todo überarbeitet
    [EinTaktReset.kicad_pcb, EinTaktReset.sch]
2018-04-18 Leiterbahnen Korrigiert
    [Steuerwerk.kicad_pcb, Steuerwerk.sch]
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2018-04-25 Weitere Leiterbahnen hinzugefügt und den überflüssigen IC entfernt
    [Steuerwerk.kicad_pcb]
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2018-05-02 footprint problem behoben falsche todo list gelöscht etc.
    [Akku.kicad_pcb, Akku.sch]
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2018-05-09 Resistoren angepasst, switches geändert, sw6 braucht noch anpassung
    [EinTaktReset.kicad_pcb, EinTaktReset.sch, _saved_EinTaktReset.sch]
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2018-06-01 falsche ferbindung am lc374 korrigiert und rbussed eingefügt, condensatoren footprinted
    [Steuerwerk.kicad_pcb, Steuerwerk.sch]
2018-06-03 Pin Anordnung von 374 korrigiert, manche Fehler gefunden und Todo Liste erweitert
    [Steuerwerk.kicad_pcb, Steuerwerk.sch]
2018-06-13 Resistor Array system begonnen aber nicht alles connectors gefunden
    [Akku.sch]
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2018-06-13 bugs behoben
    [Befehle.kicad_pcb, Befehle.sch, _saved_Befehle.sch]
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2018-06-20 bugs behoben und fertig gestellt
    [Befehle.kicad_pcb, Befehle.sch]
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2018-06-21 EinTaktReset: weiter Verbindungen gelegt, BUSCONNECTOR LINKS VERDREHT, todo updated
    [EinTaktReset.sch]
2018-06-21 EinTaktReset: Fehler in .sch behoben (Details in todo), Verbindungen großteils gelegt, todo updated
    [EinTaktReset.kicad_pcb, EinTaktReset.sch]
2018-06-22 EinTaktReset: Fehler behoben (Details in todo), PCB jetzt Fehlerfrei
    [EinTaktReset.kicad_pcb, EinTaktReset.sch]
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2018-06-27 Überflüssige LEDs entfernt, 1k Resistoren Eingebaut, Teile geordnet
    [Steuerwerk.kicad_pcb, Steuerwerk.sch]
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2019-02-07 akku sch updates for same wireing in pcb
    [Akku.kicad_pcb, Akku.sch, _saved_Akku.sch]
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2019-02-10 Eintakt libs fixed
    [Akku.kicad_pcb, Akku.sch, EinTaktReset-2019-02-09-08-03-57.sch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]
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2019-02-11 big cleanup .sch files, symbols libs, project files
    [Akku.sch, Befehle.sch, EinTaktReset.sch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]
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
